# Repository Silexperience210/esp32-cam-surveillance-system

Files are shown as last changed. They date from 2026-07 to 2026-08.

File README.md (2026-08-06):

# ESP32-CAM Surveillance System

> A complete DIY smart surveillance ecosystem: ESP32-CAM cameras with Telegram alerts, a tactile multi-camera monitoring console, automatic night lighting, video recording — and a 3D-printable wall-mount case.

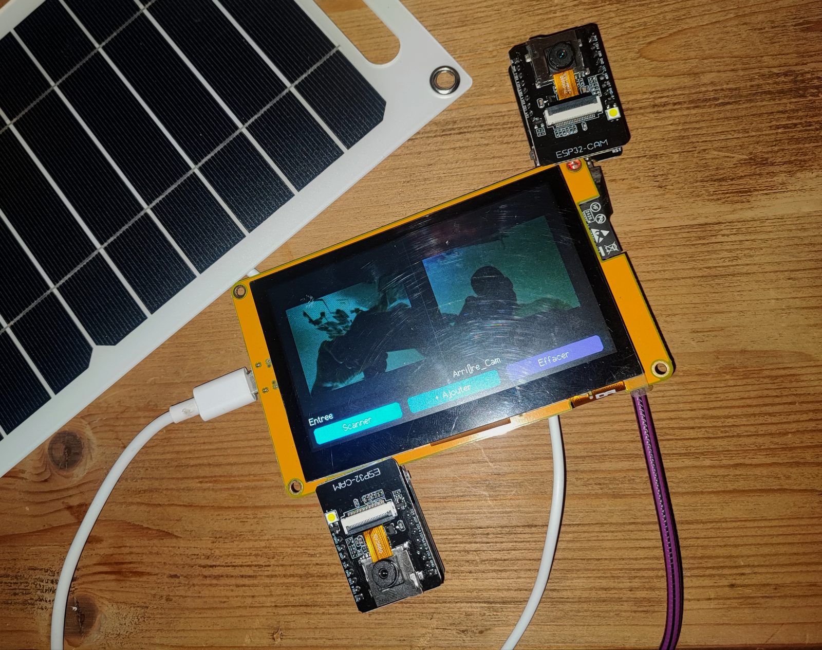
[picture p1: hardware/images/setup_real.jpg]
The running system: S3 monitor console with two ESP32-CAM cameras


---

## ✨ Features

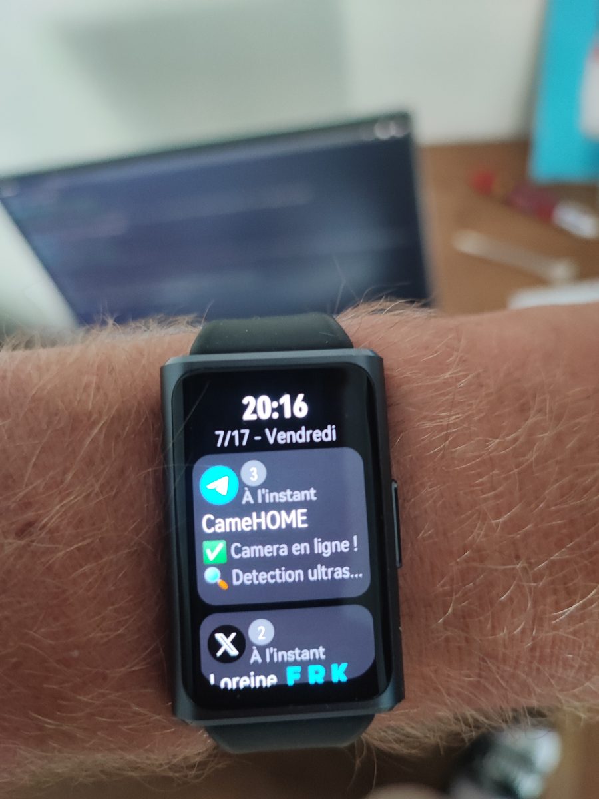
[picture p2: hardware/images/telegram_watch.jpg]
Instant Telegram alert on a smartwatch


### 📷 ESP32-CAM Camera Firmware
- **Live MJPEG streaming** in any web browser (`/stream`)
- **Telegram alerts**: instant photo + notification on presence detection (HC-SR04 ultrasonic sensor)
- **AVI video recording** to microSD while a presence is detected (5–30 s clips, 10 fps, MJPEG)
- **Two-way Telegram commands**: `/photo`, `/video`, `/status`, `/led`, `/on`, `/off`
- **LED lighting control**: manual (web / Telegram / monitor) + **automatic night mode** (lights on during alerts between 18:00 and 07:00)
- **Web configuration portal**: zero hardcoded credentials — the camera creates its own WiFi AP on first boot
- **Self-healing watchdog**: auto-restart on frozen loop, stalled stream or lost WiFi (24/7 operation)
- **Human-readable camera identity** via `/info` JSON endpoint (used by the monitor console)

_Alerts reach you anywhere — phone, desktop, even your smartwatch._

<br clear="both"/>

### 📺 ESP32-S3 Tactile Monitor (4827S043, 4.3″ 480×272)
- **Multi-camera grid view** (up to 4 cameras, round-robin refresh)
- **Tap a tile → full-screen live stream** (~10–15 fps), tap again → back to grid
- **Automatic discovery**: finds cameras instantly via **mDNS** (with IP-scan fallback)
- **On-screen keypad**: add a camera manually by IP (name auto-fetched)
- **LED toggle button** in full-screen view
- **Same web portal** for WiFi provisioning — no code editing
- Offline camera detection + auto WiFi reconnect

### 🖨️ 3D-Printed Wall-Mount Case
- Frame for the 4827S043 display + compartment for a **flat 10 000 mAh LiPo battery**
- **Dovetail wall plate**: the console slides on/off the wall in one gesture — use it as a portable tablet
- Fully **parametric OpenSCAD** source (adjust to your own battery)

### 🧠 Hermes AI Integration (NEW!)
- **YOLOv8 real-time object detection** — 80 classes, GPU-accelerated (RTX 3060), 3s inference
- **Ollama + LLaVA natural language descriptions** — « Un homme en noir tient un smartphone »
- **Motion-aware pipeline** — YOLO checks every 15s, Ollama runs only on person detection
- **Smart Telegram alerts** — silent when nothing happens, instant delivery on detection
- **AI Dashboard** — live stats, detection heatmap, multi-camera mosaic, event log
- **Detection gallery** — last 50 person snapshots with AI descriptions
- **Daily passage counter** — unique persons/vehicles with 5-min cooldown
- **Anomaly detection** — night activity, first event in 24h, activity spikes
- **Daily report** — scheduled summary at 20:00
- **Multi-camera support** — `cameras.json` config, daemon loops all enabled cameras
- **Telegram Mini App** — snapshot live, LED control, auto-refresh
- **Auto-cleanup** — keeps 7 days of snapshots, only saves person detections

> See [`hermes-ai/README.md`](hermes-ai/README.md) for setup instructions.

---

## 🏗️ System Architecture

```
                 WiFi LAN
 ┌──────────────────────────────────────────────────┐
 │                                                  │
 │   ESP32-CAM #1          ESP32-CAM #2             │
 │   ┌──────────────┐      ┌──────────────┐         │
 │   │ OV3660       │      │ OV3660       │         │
 │   │ HC-SR04      │      │ HC-SR04      │         │
 │   │ LED lighting │      │ microSD      │         │
 │   └──────┬───────┘      └──────┬───────┘         │
 │          │ MJPEG/JSON           │                │
 │          ▼                      ▼                │
 │   ┌───────────────────────────────────┐          │
 │   │  ESP32-S3 Monitor (4827S043)      │          │
 │   │  grid view · full-screen · scan   │          │
 │   └───────────────────────────────────┘          │
 │                                                  │
 └──────────────────────────────────────────────────┘
                          │
                          ▼ HTTPS
                   Telegram Bot API
              (alerts, photos, videos, commands)
```

---

## 🧰 Hardware Requirements

| Qty | Part | Notes |
|----:|---|---|
| 1+ | ESP32-CAM (AI-Thinker / Binghe) + OV3660 | One per camera |
| 1 | ESP32-4827S043 (ESP32-S3 + 4.3″ capacitive touch) | Monitor console |
| 1+ | HC-SR04 ultrasonic sensor | Presence detection (optional) |
| 1+ | microSD card (FAT32, ≤ 32 GB) | Video recording (optional) |
| 1 | LED (+ 220 Ω resistor) or onboard flash LED | Night lighting |
| 1 | Flat 10 000 mAh LiPo battery | For the portable console |
| — | FTDI programmer / USB cables | Flashing |

---

## 🚀 Getting Started

### 1. Flash the camera

```bash
arduino-cli compile --fqbn esp32:esp32:esp32cam firmware/esp32-cam
arduino-cli upload  --fqbn esp32:esp32:esp32cam -p COMx firmware/esp32-cam
```

> Flashing an ESP32-CAM requires **GPIO 0 → GND** at boot. **Remove the jumper and press RESET afterwards**, otherwise the board stays in download mode.

### 2. Configure via the web portal (no code editing!)

1. On first boot, the camera creates the WiFi network **`ESP32-CAM-Setup-xxxx`** (password: `12345678`)
2. Connect and open **http://192.168.4.1**
3. Fill in: **WiFi credentials**, **Telegram bot token + chat ID**, **camera name**, detection distance
4. The camera reboots onto your LAN and sends *"✅ Camera online"* to your Telegram

The same portal stays available anytime at `http://<camera-ip>/setup`.

### 3. Create the Telegram bot (5 min)

1. In Telegram, open **@BotFather** → `/newbot` → copy the **token**
2. Send any message to your new bot
3. Get your **chat ID** instantly from **@userinfobot**
4. Enter both values in the web portal

### 4. Flash the S3 monitor

```bash
arduino-cli lib install "LovyanGFX"
arduino-cli compile --fqbn "esp32:esp32:esp32s3:FlashSize=8M,PSRAM=opi,PartitionScheme=huge_app,CPUFreq=240,USBMode=hwcdc,CDCOnBoot=cdc" firmware/esp32-s3-monitor
arduino-cli upload  --fqbn "esp32:esp32:esp32s3:FlashSize=8M,PSRAM=opi,PartitionScheme=huge_app,CPUFreq=240,USBMode=hwcdc,CDCOnBoot=cdc" -p COMx firmware/esp32-s3-monitor
```

Board options: **ESP32S3 Dev Module**, PSRAM **OPI**, Flash **8MB** (N8R8) or 16MB (N16R8), partition **Huge APP**, USB CDC On Boot **Enabled**.

On first boot the monitor shows its own provisioning screen (`ESP32-Viewer-Setup-xxxx`, same procedure). Then tap **[Scanner]** — it discovers your cameras automatically.

---

## 🤖 Telegram Commands

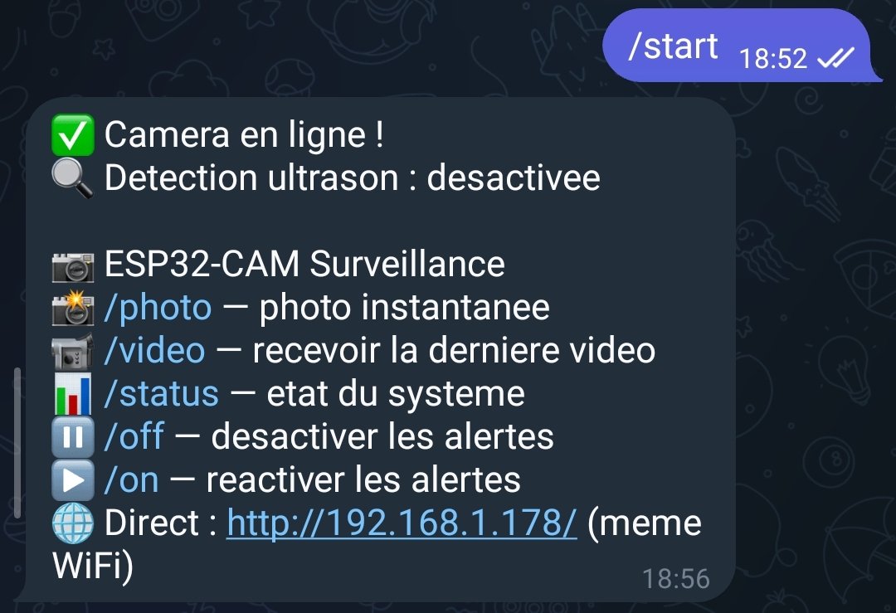
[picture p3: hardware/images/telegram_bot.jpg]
Telegram bot: boot message and command list


| Command | Action |
|---|---|
| `/photo` | Instant photo from the camera |
| `/video` | Receive the last recorded AVI clip |
| `/led` `/ledon` `/ledoff` `/ledauto` | Lighting control |
| `/on` `/off` | Enable / disable automatic alerts |
| `/status` | IP, uptime, distance, SD, videos, LED, night mode |
| `/help` | Command list |

## 🌐 Camera HTTP API

| Endpoint | Description |
|---|---|
| `GET /` | Web dashboard (live view + links) |
| `GET /stream` | MJPEG live stream |
| `GET /capture` | Single JPEG snapshot |
| `GET /video` | Download last AVI recording |
| `GET /list` | List/download all recordings |
| `GET /led?state=on\|off\|toggle\|auto` | Lighting control (JSON) |
| `GET /info` | Camera identity + state (JSON) |
| `GET /setup` | Configuration portal |

---

## 🔌 Wiring

### HC-SR04 ultrasonic sensor (optional — presence detection)

```
HC-SR04          ESP32-CAM
-------          ---------
VCC    ────────► 5V
GND    ────────► GND
TRIG   ────────► GPIO 13
ECHO   ──[1kΩ]──► GPIO 12 ──[2kΩ]──► GND     ← voltage divider (mandatory)
```

> ⚠️ ECHO outputs 5 V — the divider protects the 3.3 V GPIO. The microSD slot works in **1-bit mode**, leaving GPIO 12/13 free.

Then set `DETECTION_ULTRASON = true` in the camera firmware and reflash.

### LED lighting

Use the onboard flash LED (GPIO 4) directly, or wire an external LED:

```
LED anode (+) ──[220Ω]── GPIO 4
LED cathode (−) ──────── GND
```

Both light up together — perfect for night illumination. For a high-power LED, drive it through an NPN transistor.

**Automatic night mode**: on any alert between **18:00 and 07:00**, the LED turns on for the photo and the whole video, then switches off. Manual control always takes priority.

---

## 🖨️ 3D-Printed Cases

### Monitor case (wall-mount / tabletop)

Parametric OpenSCAD source + ready-to-print STLs in [`hardware/case/`](hardware/case).

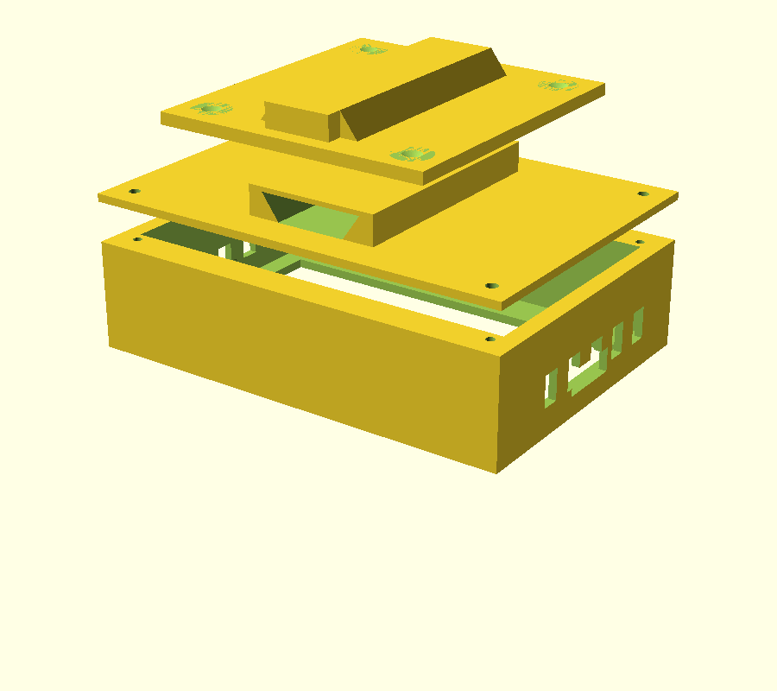
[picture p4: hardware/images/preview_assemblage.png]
Case preview


| Part | File | Print orientation |
|---|---|---|
| Main body | `boitier_corps.stl` | Screen frame facing the bed |
| Back cover (dovetail female) | `boitier_couvercle.stl` | Rail facing up |
| Wall plate (dovetail male) | `boitier_plaque_murale.stl` | Flat, rail facing up |

- No supports needed · PLA/PETG · 0.2 mm layers · 3 walls · 20 % infill
- Assembly: 4× M2 self-tapping screws (cover), 4× wood screws (wall plate)
- **Battery**: measure yours and adjust `bat_w / bat_h / bat_d` in `boitier_4827S043.scad`, then re-export:

```bash
openscad -o boitier_corps.stl -D part=1 boitier_4827S043.scad
```

### Camera case (ESP32-CAM + programming board)

Snap-fit enclosure for an ESP32-CAM stacked on its **ESP32-CAM-MB USB programming board** — thin **1.6 mm walls** with a vertical ribbed texture. STLs + parametric source in [`hardware/case-esp32cam/`](hardware/case-esp32cam).

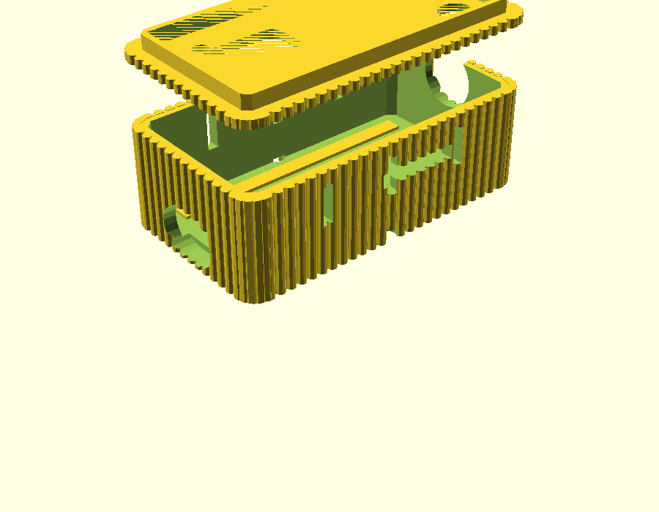
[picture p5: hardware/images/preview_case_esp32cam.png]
Camera case preview


| Part | File | Print orientation |
|---|---|---|
| Body | `esp32cam_case_body.stl` | Upright, bottom on the bed |
| Friction lid | `esp32cam_case_lid.stl` | Plate on the bed |

- No supports · PLA/PETG · 0.2 mm layers · ~1h30 total
- Lens / flash / micro-USB / microSD / antenna openings + 2× M3 mount holes
- **Measure your stack** and adjust `in_l / in_w / in_h`, `cam_z`, `lid_clr`… at the top of `esp32cam_mb_case.scad`

---

## 📁 Project Structure

```
esp32-cam-surveillance-system/
├── firmware/
│   ├── esp32-cam/              # Camera firmware (Arduino)
│   │   ├── esp32-cam-surveillance.ino
│   │   └── avi_writer.h        # Minimal MJPEG→AVI writer
│   └── esp32-s3-monitor/       # Tactile monitor firmware (LovyanGFX)
│       └── esp32-viewer-s3.ino
├── hardware/
│   ├── case/                   # Monitor case (OpenSCAD + STLs)
│   ├── case-esp32cam/          # Camera case for ESP32-CAM + MB board
│   └── images/                 # Renders & sample captures
├── docs/
├── LICENSE
└── README.md
```

## 🧠 Design Notes

- **Grid refresh** uses per-camera `/capture` round-robin (light on bandwidth); **full-screen** uses the dedicated MJPEG `/stream`.
- The microSD slot runs in **1-bit SD_MMC mode**, keeping GPIO 12/13 free for the ultrasonic sensor.
- AVI files use a minimal MJPEG writer (`avi_writer.h`) — playable in VLC and shareable via Telegram.
- All credentials persist in **NVS (Preferences)** — survives power loss, no SD dependency.
- The watchdog task runs on the **second core**, so even a fully frozen main loop gets restarted.

## 🗺️ Roadmap

- [ ] PIR wake-up + deep sleep for battery-powered cameras
- [ ] Home Assistant integration (MJPEG camera + MQTT alerts)
- [ ] Remote access via Tailscale
- [ ] Auto full-screen on the monitor when a camera triggers
- [x] mDNS camera auto-discovery (instant — cameras also reachable at `http://<name>.local`)

## ⚠️ Disclaimer

This is a DIY hobby project. Do not use it as your only security system. Respect privacy laws when installing cameras.

## 📄 License

MIT License — see [LICENSE](LICENSE).

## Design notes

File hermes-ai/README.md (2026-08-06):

# Hermes AI — Intégration ESP32-CAM

Pipeline IA complet pour caméra de surveillance ESP32-CAM, piloté par l'agent Hermes.

## 🧠 Fonctionnalités

- **Motion detection** → ne déclenche l'analyse que si mouvement (CPU, ~1.4s)
- **YOLOv8** → détection 80 classes (personne, voiture, animal...) en ~3s GPU
- **Ollama + LLaVA** → descriptions naturelles en français (~5s)
- **Alertes intelligentes** → ne notifie que personne/véhicule/animal
- **Compteur de passages** → cooldown 5 min entre chaque comptage
- **Anomalies** → personne la nuit, pic d'activité
- **Dashboard web** → stats, événements, heatmap, toggle ON/OFF
- **Mini App Telegram** → snapshot live, contrôle LED
- **Silencieux si RAS** → 0 message si rien ne se passe

## 📁 Structure

```
hermes-ai/
├── scripts/
│   ├── ai_eye.py          → Pipeline IA principal (motion → YOLO → Ollama → alerte)
│   ├── camera_client.py   → Client HTTP pour l'ESP32-CAM
│   ├── eye_proxy.py       → Proxy Flask (Mini App + API dashboard)
│   ├── ai_smart_cron.sh   → Cron silencieux (alerte uniquement)
│   ├── camera_health.sh   → Health check caméra
│   └── ai_cleanup.sh      → Nettoyage snapshots >7j
└── dashboards/
    ├── eye.html            → Dashboard full (stream MJPEG)
    ├── eye_telegram.html   → Mini App Telegram (mobile)
    └── ai_dashboard.html   → Dashboard IA (stats, events, heatmap)
```

## 🚀 Quick Start

```bash
# 1. Installer les dépendances
uv pip install ultralytics torch torchvision Pillow numpy flask

# 2. Ollama (pour LLaVA)
ollama pull llava-llama3:8b

# 3. Lancer le proxy
python3 eye_proxy.py

# 4. Activer l'IA
python3 ai_eye.py --on

# 5. Analyse unique
python3 ai_eye.py

# 6. Status
python3 ai_eye.py --status
```

## 🔧 Commandes

| Commande | Action |
|---|---|
| `ai_eye.py --on` | Activer l'IA |
| `ai_eye.py --off` | Suspendre l'IA |
| `ai_eye.py --status` | État GPU, événements, snapshots |
| `ai_eye.py --cleanup 7` | Nettoyer les fichiers >7 jours |
| `camera_client.py capture` | Photo instantanée |
| `camera_client.py motion` | Détection de mouvement |
| `camera_client.py health` | Vérifier si la caméra est en ligne |

## 🌐 Endpoints (proxy Flask :8084)

| URL | Description |
|-----|---|
| `/` | Mini App Telegram |
| `/dashboard` | Dashboard IA |
| `/api/capture` | Snapshot JPEG |
| `/api/info` | Infos caméra |
| `/api/led?state=toggle` | Contrôle LED |
| `/api/ai/status` | Statut IA (GPU, events) |
| `/api/ai/events` | Derniers événements |
| `/api/ai/counter` | Compteur passages |
| `/api/ai/report` | Rapport 24h |
| `/api/ai/toggle` | ON/OFF IA |
| `/api/ai/analyze` | Forcer analyse |

## 📊 Crons recommandés

| Cron | Fréquence | Script |
|---|---|---|
| AI Eye | 5 min | `ai_smart_cron.sh` |
| Health check | 5 min | `camera_health.sh` |
| Nettoyage | 3h du matin | `ai_cleanup.sh` |
| Rapport quotidien | 20h | prompt LLM → `/api/ai/report` |

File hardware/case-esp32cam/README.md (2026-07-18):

# 📦 ESP32-CAM + ESP32-CAM-MB Case

Two-piece enclosure for an **ESP32-CAM (AI-Thinker) stacked on its ESP32-CAM-MB USB programming board** — thin **1.6 mm walls** with a clean **vertical ribbed texture** outside.

exploded preview

## 📁 Files

| File | Description |
|---|---|
| `esp32cam_mb_case.scad` | Fully **parametric** OpenSCAD source |
| `esp32cam_case_body.stl` | Main body — 59.3 × 33 × 18.7 mm |
| `esp32cam_case_lid.stl` | Snap-friction lid — 4.2 mm |
| `esp32cam_case_print_all.stl` | Both parts side by side (single plate) |

## 🖨️ Printing

- **No supports** — body upright (bottom on the bed), lid plate on the bed
- PLA or PETG · **0.2 mm** layers · 3–4 perimeters (1.6 mm walls = 4 × 0.4 lines)
- Infill doesn't matter (walls are solid)
- ~1h30 total print time

## 📐 Dimensions

- Outside: **59.3 × 33 × 20.2 mm** (ribs included)
- Inside: 54.5 × 28.2 × 17 mm (fits the MB board 52.5 × 26 mm + stacked camera)

## ✨ Features

- Ø11 mm **lens window** (front face)
- **Flash LED window** in the lid (`top_flash`, AI-Thinker LED shines upwards — set `front_flash=true` if yours faces forward)
- **Micro-USB** slot (rear face) + pin-hole for the MB **reset button**
- Side **microSD slot** — insert/remove the card without opening the case
- **WiFi antenna window** in the lid (better signal)
- 6 side **ventilation slots**
- 2× **M3 holes** in the bottom (wall/desk mounting)
- **Friction-fit lid** — no screws, no hardware

## ⚠️ Measure before printing

Default dimensions match the standard AI-Thinker + MB stack. Check yours and adjust at the top of `esp32cam_mb_case.scad`:

| Parameter | Default | Check |
|---|---|---|
| `in_l / in_w / in_h` | 54.5 / 28.2 / 17 | Your MB board size + total stack height |
| `cam_z` | 14.5 | Lens center height (from inside bottom) |
| `cam_y` | 0 | Lens lateral offset |
| `flash_x / flash_y` | 20 / -8.5 | Flash LED position |
| `usb_z` | 5 | Micro-USB connector height |
| `sd_x / sd_z` | 5 / 12.3 | microSD slot position (left wall) |
| `lid_clr` | 0.25 | Lid clearance — **+0.05 if too tight, -0.05 if too loose** |

## 🔧 Re-export STLs

```bash
openscad -o esp32cam_case_body.stl -D part=1 esp32cam_mb_case.scad   # body
openscad -o esp32cam_case_lid.stl  -D part=2 esp32cam_mb_case.scad   # lid
openscad -o esp32cam_case_print_all.stl -D part=3 esp32cam_mb_case.scad  # both
```

## 🎨 Texture tuning

- `rib_step = 2.1` → rib spacing (larger = airier, smaller = finer)
- `rib_r = 0.85` → rib depth
- `rib = false` → smooth case

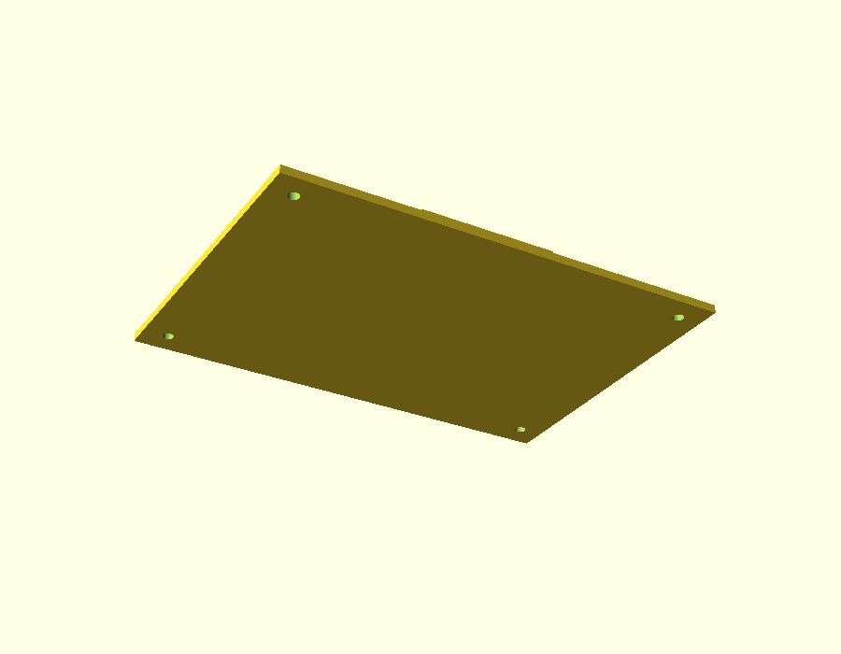
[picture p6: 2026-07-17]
hardware/images/preview_couvercle.png

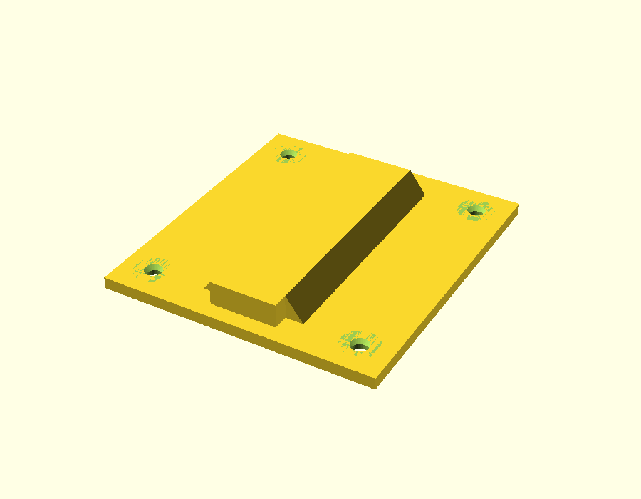
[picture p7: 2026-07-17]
hardware/images/preview_plaque.png

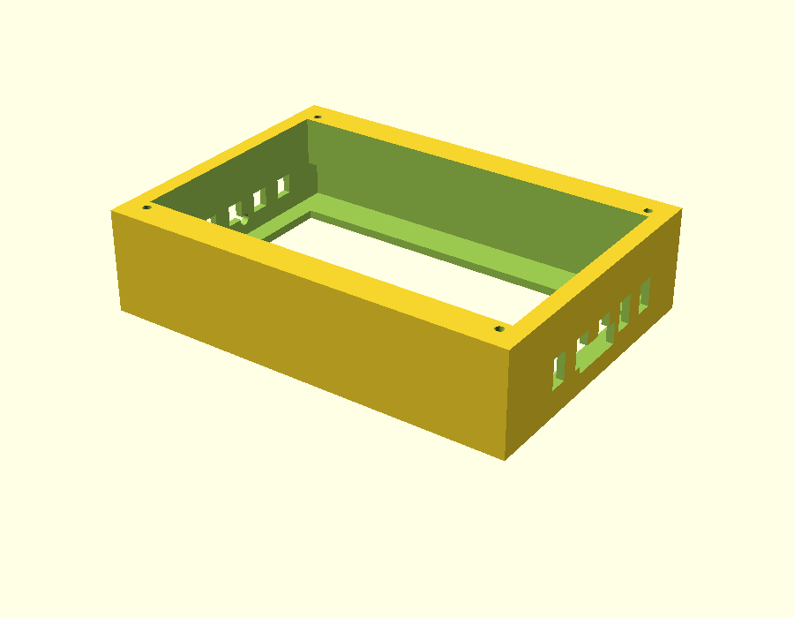
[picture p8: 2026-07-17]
hardware/images/preview_corps.png

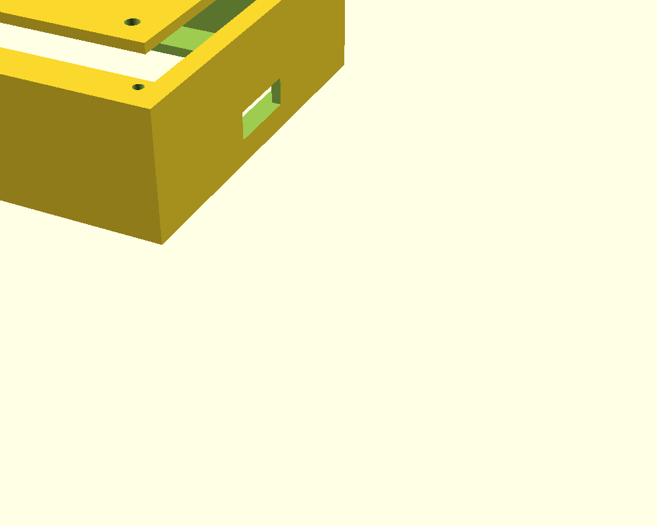
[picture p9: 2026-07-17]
hardware/images/preview_boitier.png

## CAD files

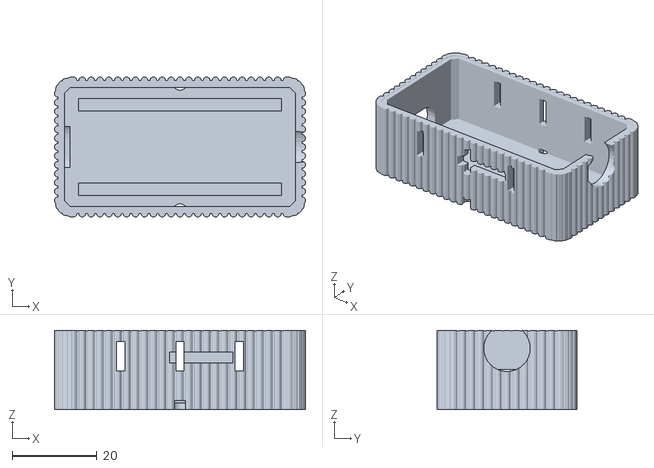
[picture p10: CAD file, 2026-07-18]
hardware/case-esp32cam/esp32cam_case_body.stl
59.3 x 33.0 x 18.7

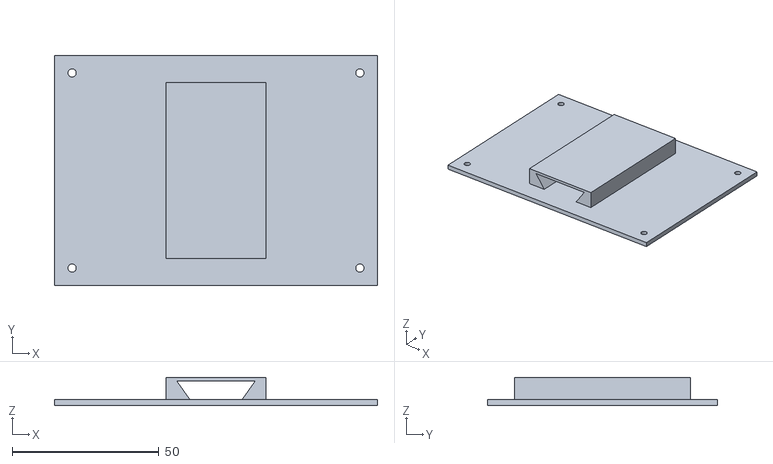
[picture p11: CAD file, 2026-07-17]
hardware/case/boitier_couvercle.stl
109.9 x 78.4 x 9.55

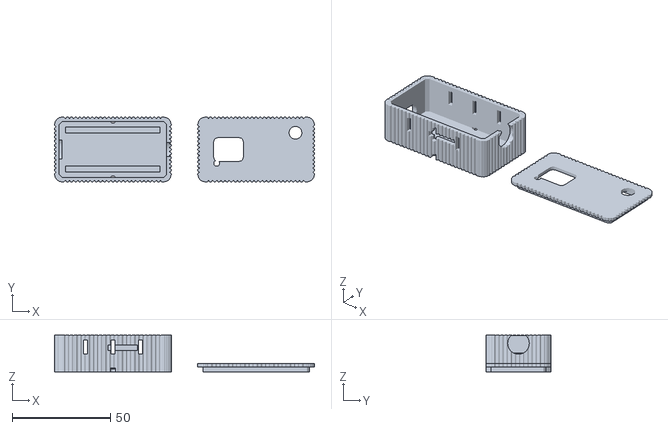
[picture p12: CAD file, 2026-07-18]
hardware/case-esp32cam/esp32cam_case_print_all.stl
132.0 x 33.0 x 18.7

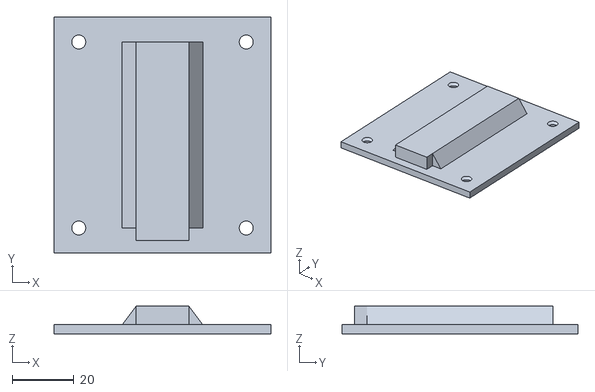
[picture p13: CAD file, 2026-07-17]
hardware/case/boitier_plaque_murale.stl
70.0 x 76.0 x 9.00

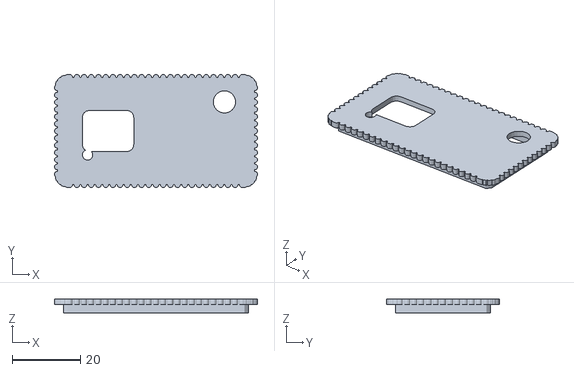
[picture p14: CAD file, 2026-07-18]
hardware/case-esp32cam/esp32cam_case_lid.stl
59.3 x 33.0 x 4.19

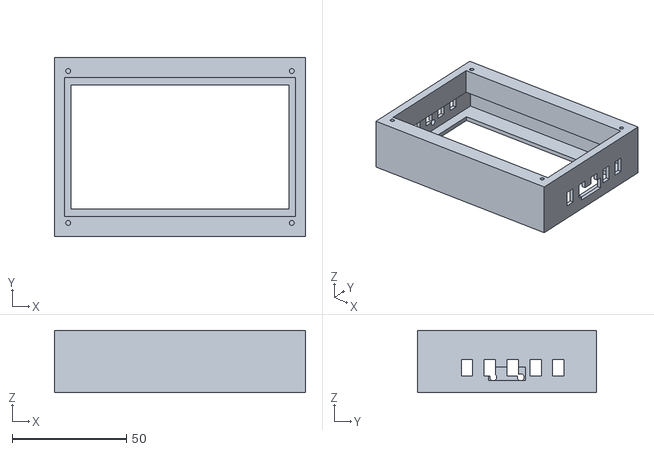
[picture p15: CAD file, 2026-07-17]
hardware/case/boitier_corps.stl
109.9 x 78.4 x 27.2

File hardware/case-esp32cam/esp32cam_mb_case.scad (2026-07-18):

// =====================================================================
//  BOITIER ESP32-CAM + CARTE PROGRAMMATION ESP32-CAM-MB
//  Parois fines 1.6 mm - Texture stries verticales - Couvercle friction
//  IMPRESSION : corps + couvercle, aucun support, PLA/PETG 0.2 mm
// =====================================================================
//  ⚠️  COTES PAR DÉFAUT = montage standard AI-Thinker + MB.
//      MESURE ton empilage et ajuste les variables ci-dessous.
// =====================================================================

// ---------- CHOIX DE LA PIÈCE ----------
part = 3;        // 1 = corps | 2 = couvercle | 3 = les deux (impression) | 4 = éclaté (vérif)

// ---------- COTES INTERNES (À MESURER) ----------
in_l = 54.5;     // longueur interne  (carte MB ≈ 52.5 + jeu)
in_w = 28.2;     // largeur interne   (carte MB ≈ 26   + jeu)
in_h = 17.0;     // hauteur interne   (empilage MB + ESP32-CAM + nappe)

wall   = 1.6;    // épaisseur des parois  ← ta demande
corner = 3.0;    // rayon des coins extérieurs

// ---------- CAMÉRA (face avant) ----------
cam_z  = 14.5;   // hauteur du centre de la lentille (depuis le fond interne)
cam_y  = 0;      // décalage latéral lentille (0 = centrée)
lens_d = 11;     // diamètre fenêtre lentille

// ---------- LED FLASH GPIO4 ----------
top_flash   = true;    // fenêtre dans le COUVERCLE (LED AI-Thinker émet vers le haut)
front_flash = false;   // fenêtre dans la face avant (si LED orientée avant)
flash_x  = 20;         // position X de la LED (vers l'avant, côté connecteur cam)
flash_y  = -8.5;       // position Y de la LED
flash_d  = 6.5;        // diamètre fenêtre flash

// ---------- USB (face arrière) ----------
usb_w = 13;      // largeur fenêtre micro-USB
usb_h = 9;       // hauteur fenêtre
usb_z = 5;       // hauteur du centre (connecteur au bas de la MB)

// ---------- OPTIONS ----------
vent         = true;   // fentes de ventilation sur les côtés
sd_slot      = true;   // fente carte microSD (paroi gauche)
sd_x   = 5;  sd_z = 12.3;  sd_len = 15;  sd_h = 2.6;   // position fente SD
reset_hole   = true;   // trou d'aiguille pour bouton reset MB (couvercle)
reset_x = -20;  reset_y = 7;  reset_d = 3;
ant_window   = true;   // fenêtre antenne WiFi (couvercle, améliore le signal)
ant_x = -14; ant_w = 15; ant_h = 12;
mount_holes  = true;   // 2 trous M3 dans le fond (fixation)
mount_spacing = 30;

// ---------- COUVERCLE ----------
lid_lip = 2.6;   // hauteur de la lèvre d'emboîtement
lid_clr = 0.25;  // jeu friction (±0.05 selon imprimante — resserre si trop lâche)

// ---------- TEXTURE STRIES ----------
rib      = true;
rib_step = 2.1;  // espacement des stries (mm)
rib_r    = 0.85; // rayon des stries = profondeur du relief

// =====================================================================
//  CALCULS
// =====================================================================
out_l  = in_l + 2*wall;
out_w  = in_w + 2*wall;
body_h = in_h + wall;           // hauteur du corps (fond compris)

// =====================================================================
//  MODULES DE BASE
// =====================================================================
// Profil 2D arrondi du boîtier ; d>0 grossit, d<0 rétrécit
module profil(d=0) {
  offset(r = corner + d)
    square([out_l - 2*corner, out_w - 2*corner], center = true);
}

// Coque du corps (bac ouvert)
module coque() {
  difference() {
    linear_extrude(body_h) profil(0);
    translate([0, 0, wall])
      linear_extrude(body_h) profil(-wall);
  }
}

// Rails de support de la carte MB (évite les soudures des headers)
module rails() {
  for (s = [-1, 1])
    translate([0, s * 10, wall])
      cube([48, 3, 1.2], center = true);
}

// Stries verticales : cylindres posés EXACTEMENT sur le périmètre
// (segments droits + quarts de cercle aux coins -> ancrage garanti)
rl = out_l/2 - corner;      // demi-longueur des parties droites
rw = out_w/2 - corner;
nl = floor(rl / rib_step);  // nb stries par demi-face longue
nw = floor(rw / rib_step);  // nb stries par demi-face courte
na = max(4, round(PI*corner/2 / rib_step)); // stries par quart de coin

module strie(x, y, h)
  translate([x, y, -0.1]) cylinder(r = rib_r, h = h + 0.2, $fn = 10);

module stries(h) {
  intersection() {
    union() {
      // faces longues (y = ±out_w/2)
      for (s = [-1, 1], i = [-nl : nl])
        strie(i * rib_step, s * out_w/2, h);
      // faces courtes (x = ±out_l/2)
      for (s = [-1, 1], i = [-nw : nw])
        strie(s * out_l/2, i * rib_step, h);
      // quarts de cercle aux 4 coins
      for (cx = [-1, 1], cy = [-1, 1], a = [0 : na])
        strie(cx * (rl + corner * cos(a * 90 / na)),
              cy * (rw + corner * sin(a * 90 / na)), h);
    }
    // on ne garde que ce qui dépasse de la surface (ancrage 0.5 mm)
    difference() {
      linear_extrude(h + 0.2) profil(rib_r * 0.95);
      translate([0, 0, -0.1]) linear_extrude(h + 0.4) profil(-0.5);
    }
  }
}

// =====================================================================
//  OUVERTURES DU CORPS
// =====================================================================
module ouvertures_corps() {
  // --- Fenêtre lentille (face avant +X) ---
  translate([out_l/2, cam_y, cam_z])
    rotate([0, 90, 0])
      cylinder(d = lens_d, h = wall*3 + 1, center = true, $fn = 32);

  // --- Fenêtre flash LED face avant (option) ---
  if (front_flash)
    translate([out_l/2, flash_y, cam_z])
      rotate([0, 90, 0])
        cylinder(d = flash_d, h = wall*3 + 1, center = true, $fn = 24);

  // --- Fenêtre micro-USB (face arrière -X), oblongue ---
  translate([-out_l/2, 0, usb_z])
    rotate([0, 90, 0])
      hull()
        for (s = [-1, 1])
          translate([0, s * (usb_w - usb_h)/2, 0])
            cylinder(d = usb_h, h = wall*3 + 1, center = true, $fn = 24);

  // --- Fentes de ventilation (2 grands côtés, partie haute) ---
  if (vent)
    for (s = [-1, 1], j = [-1, 0, 1])
      translate([j * 14, s * out_w/2, body_h - 6])
        cube([2, wall*3 + 1, 7], center = true);

  // --- Fente carte microSD (paroi gauche -Y) ---
  if (sd_slot)
    translate([sd_x, -out_w/2, sd_z])
      cube([sd_len, wall*3 + 1, sd_h], center = true);

  // --- Trous de fixation M3 dans le fond ---
  if (mount_holes)
    for (s = [-1, 1])
      translate([0, s * mount_spacing/2, -0.5])
        cylinder(d = 3.2, h = wall + 1, $fn = 24);
}

// =====================================================================
//  CORPS
// =====================================================================
module corps() {
  difference() {
    union() {
      coque();
      rails();
      if (rib) stries(body_h);
    }
    ouvertures_corps();
  }
}

// =====================================================================
//  COUVERCLE (emboîtement friction)
// =====================================================================
module couvercle() {
  difference() {
    union() {
      // plaque
      linear_extrude(wall) profil(0);
      // lèvre d'emboîtement (rentre dans le corps)
      translate([0, 0, wall - 0.01])
        difference() {
          linear_extrude(lid_lip) profil(-wall - lid_clr);
          linear_extrude(lid_lip) profil(-wall - lid_clr - 1.1);
        }
      // stries sur le pourtour de la plaque
      if (rib)
        intersection() {
          stries(wall);
          linear_extrude(wall) profil(rib_r);
        }
    }
    // --- fenêtre flash LED (dessus) ---
    if (top_flash)
      translate([flash_x, flash_y, -0.5])
        cylinder(d = flash_d, h = wall + 1, $fn = 24);
    // --- trou bouton reset MB ---
    if (reset_hole)
      translate([reset_x, reset_y, -0.5])
        cylinder(d = reset_d, h = wall + 1, $fn = 20);
    // --- fenêtre antenne WiFi ---
    if (ant_window)
      translate([ant_x, 0, -0.5])
        hull()
          for (sx = [-1, 1], sy = [-1, 1])
            translate([sx * (ant_w/2 - 2), sy * (ant_h/2 - 2), 0])
              cylinder(r = 2, h = wall + 1, $fn = 16);
  }
}

// =====================================================================
//  RENDU
// =====================================================================
if (part == 1) corps();
else if (part == 2)
  translate([0, 0, wall + lid_lip]) rotate([180, 0, 0]) couvercle(); // à plat pour impression
else if (part == 3) {
  corps();
  translate([out_l/2 + 15 + out_l/2, 0, wall + lid_lip])
    rotate([180, 0, 0]) couvercle();
}
else if (part == 4) { // éclaté de vérification
  corps();
  translate([0, 0, body_h + 12]) couvercle();
}

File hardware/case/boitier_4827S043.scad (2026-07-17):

// ============================================================
// BOITIER ESP32-4827S043 + Batterie 10000mAh + Fixation murale
// Moniteur multi-cameras — version "tablette murale detachable"
// ============================================================
// 3 pieces a imprimer :
//   part=1 -> corps (cadre ecran + logement carte + batterie)
//   part=2 -> couvercle arriere (avec rail femelle)
//   part=3 -> plaque murale (avec rail male, a visser au mur)
//
// Le boitier glisse de haut en bas sur la plaque murale et se
// detache facilement pour etre utilise comme tablette.
// ============================================================

part = 0;   // 0 = vue eclatee, 1/2/3 = piece a exporter

// ---------- MESURES A AJUSTER (mm) ----------
pcb_w = 105.5;   // largeur carte 4827S043
pcb_h = 74.0;    // hauteur carte
pcb_d = 12.0;    // epaisseur carte+ecran+composants
scr_w = 95.5;    // fenetre ecran visible (95.04 + jeu)
scr_h = 54.5;    // (53.86 + jeu)
scr_offx = 0;    // decalage fenetre ecran X si besoin
scr_offy = 0;    // decalage fenetre ecran Y si besoin

// Batterie 10000mAh plate LiPo : MESURE LA TIENNE et ajuste !
bat_w = 101.0;   // longueur batterie
bat_h = 61.0;    // largeur batterie
bat_d = 13.0;    // epaisseur batterie

wall   = 2.0;    // epaisseur parois laterales
front  = 2.2;    // epaisseur face avant (cadre)
gap    = 0.4;    // jeu d'assemblage carte

// ---------- dimensions calculees ----------
ext_w = pcb_w + 2*wall + gap;          // largeur externe boitier
ext_h = pcb_h + 2*wall + gap;          // hauteur externe
depth = front + pcb_d + bat_d + wall;  // profondeur totale ~29mm

// ---------- rail queue d'aronde (murale) ----------
rail_len  = 60;   // longueur du rail (glissement vertical)
rail_wb   = 26;   // largeur a la base (contre la plaque)
rail_wt   = 17;   // largeur au sommet
rail_h    = 6;    // hauteur du rail
rail_play = 0.35; // jeu coulissant

// ---------- vis ----------
boss_d  = 6;      // diametre boss de fixation couvercle
screw_d = 2.2;    // trou vis M2 auto-taraudeuse
mwall_d = 4.5;    // trous vis murale (vis bois 4mm)

$fn = 48;

// ============================================================
module corps() {
  difference() {
    union() {
      translate([-ext_w/2, -ext_h/2, 0])
        cube([ext_w, ext_h, depth - wall]);
      for (x = [-1, 1], y = [-1, 1])
        translate([x*(ext_w/2 - wall - boss_d/2 - 1),
                   y*(ext_h/2 - wall - boss_d/2 - 1), 0])
          cylinder(d = boss_d, h = depth - wall);
    }
    // cavite carte (derriere le cadre avant)
    translate([-pcb_w/2 - gap/2, -pcb_h/2 - gap/2, front])
      cube([pcb_w + gap, pcb_h + gap, pcb_d + 0.2]);
    // cavite batterie
    translate([-bat_w/2, -bat_h/2, front + pcb_d])
      cube([bat_w, bat_h, bat_d + 0.2]);
    // fenetre ecran
    translate([-scr_w/2 + scr_offx, -scr_h/2 + scr_offy, -0.1])
      cube([scr_w, scr_h, front + 0.2]);
    // ouverture USB-C (cote droit)
    translate([ext_w/2 - wall - 0.1, -8, front + pcb_d/2 - 3])
      cube([wall + 0.2, 16, 6]);
    // trous acces boutons RESET / BOOT (cote gauche)
    for (y = [-6, 6])
      translate([-ext_w/2 - 0.1, y, front + pcb_d/2 - 1.5])
        rotate([0, 90, 0]) cylinder(d = 3, h = wall + 0.2);
    // trous vis couvercle dans les boss
    for (x = [-1, 1], y = [-1, 1])
      translate([x*(ext_w/2 - wall - boss_d/2 - 1),
                 y*(ext_h/2 - wall - boss_d/2 - 1), depth - wall - 8])
        cylinder(d = screw_d, h = 8.1);
    // fentes de ventilation laterales (2 grands cotes, zone carte)
    for (y = [-20, -10, 0, 10, 20]) {
      translate([ext_w/2 - wall - 0.1, y, front + pcb_d/2 - 1])
        cube([wall + 0.2, 5, 8]);
      translate([-ext_w/2 - 0.1, y, front + pcb_d/2 - 1])
        cube([wall + 0.2, 5, 8]);
    }
  }
}

// ============================================================
// Rainure femelle : ETROITE a l'ouverture, LARGE au fond
// (complementaire du rail male : large a la base, etroit au sommet)
module rail_femelle(l) {
  linear_extrude(height = l)
    polygon([[-rail_wt/2 - rail_play, 0],
             [-rail_wb/2 - rail_play, rail_h + rail_play],
             [ rail_wb/2 + rail_play, rail_h + rail_play],
             [ rail_wt/2 + rail_play, 0]]);
}

module couvercle() {
  joug_h = rail_h + rail_play + 1.2;
  difference() {
    union() {
      // plaque
      translate([-ext_w/2, -ext_h/2, 0])
        cube([ext_w, ext_h, wall]);
      // joug autour du rail femelle
      translate([-rail_wb/2 - 4, -rail_len/2, wall])
        cube([rail_wb + 8, rail_len, joug_h]);
    }
    // rainure femelle traversante (le long de Y, profil dans XZ)
    translate([0, rail_len/2 + 0.1, wall])
      rotate([90, 0, 0])
        rail_femelle(rail_len + 0.2);
    // trous vis aux coins (alignes sur les boss du corps)
    for (x = [-1, 1], y = [-1, 1])
      translate([x*(ext_w/2 - wall - boss_d/2 - 1),
                 y*(ext_h/2 - wall - boss_d/2 - 1), -0.1])
        cylinder(d = screw_d + 0.6, h = wall + 0.2);
  }
}

// ============================================================
module rail_male(l) {
  // trapeze : base large (contre plaque), sommet etroit
  linear_extrude(height = l)
    polygon([[-rail_wb/2, 0], [-rail_wt/2, rail_h],
             [ rail_wt/2, rail_h], [ rail_wb/2, 0]]);
}

module plaque_murale() {
  pw = 70; ph = rail_len + 16; pt = 3;   // plaque 70 x 76 x 3
  difference() {
    union() {
      translate([-pw/2, -ph/2, 0])
        cube([pw, ph, pt]);
      // rail male COUCHE le long de Y (boitier glisse de haut en bas)
      translate([0, rail_len/2, pt])
        rotate([90, 0, 0])
          rail_male(rail_len);
      // butee basse (fin de course du boitier)
      translate([-rail_wt/2, -rail_len/2 - 4, pt])
        cube([rail_wt, 4, rail_h]);
    }
    // 4 trous de vis fraises pour fixation murale
    for (x = [-1, 1], y = [-1, 1])
      translate([x*(pw/2 - 8), y*(ph/2 - 8), -0.1]) {
        cylinder(d = mwall_d, h = pt + 0.2);
        translate([0, 0, pt - 1.6])
          cylinder(d1 = mwall_d, d2 = mwall_d*2.1, h = 1.7);   // fraisage
      }
  }
}

// ============================================================
// ---------- rendu ----------
if (part == 1) {
  corps();
} else if (part == 2) {
  couvercle();
} else if (part == 3) {
  plaque_murale();
} else {
  // vue eclatee
  corps();
  translate([0, 0, depth + 8]) couvercle();
  translate([0, 0, depth + 30]) plaque_murale();
}

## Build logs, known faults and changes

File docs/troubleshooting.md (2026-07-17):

# Troubleshooting

Real issues encountered and solved while building this project.

## Camera stays in "waiting for download" (no WiFi AP appears)

**Symptom**: serial log shows `boot:0x3 (DOWNLOAD_BOOT)` / `waiting for download`.
**Cause**: the GPIO 0 → GND flashing jumper is still in place.
**Fix**: remove the jumper, press RESET. Flashing jumper is only needed during upload.

## Camera/monitor unreachable on the LAN (works on other devices)

**Symptom**: `ping` and browser fail from one PC, but the device answers from others.
**Cause**: a VPN client (e.g. Tailscale) has installed a route for your LAN subnet (`192.168.1.0/24`), hijacking local traffic into the tunnel.
**Fix**: disable the subnet route in the VPN client (Tailscale → *Use Tailscale subnets* → uncheck your LAN), or disconnect the VPN.

## Telegram commands are ignored (but bot answers at boot)

**Cause**: chat ID mismatch — e.g. wrong value, or a parsing bug. The camera only accepts commands from the configured `chat_id`.
**Fix**: verify the chat ID with **@userinfobot** and re-enter it in `http://<ip>/setup`.

## Camera probe fails from the monitor ("no camera at this IP")

**Symptom**: manual add fails while the camera works in a browser.
**Cause**: probe timeout too short — the camera is busy streaming to another client.
**Fix**: close other streams and retry; the firmware ships with a 2 s timeout for manual add and 600 ms for network scans.

## Viewer screen is white after flashing

**Cause**: wrong PSRAM setting.
**Fix**: recompile with `PSRAM=opi` and the correct flash size (8M for N8R8, 16M for N16R8).

## Touch works but axes are inverted

**Fix**: adjust `cfg.offset_rotation` (0–7) in the LGFX touch config block of the monitor firmware.

## Brownouts / random restarts while streaming

**Cause**: power supply too weak. Streaming + WiFi peaks > 500 mA.
**Fix**: use a dedicated 5 V / 2 A supply and a short, good-quality cable.

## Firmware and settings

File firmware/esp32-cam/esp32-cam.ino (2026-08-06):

/*
 * ESP32-CAM Surveillance intelligente v3 — CORRIGÉ COMPLET
 * ----------------------------------------------------------
 * Corrections (audit Kimi + Claude Opus) :
 *   • Mutex caméra (camGet/camReturn) — driver non réentrant
 *   • lastUpdateId persisté en NVS — évite boucle reboot infinie
 *   • Mode AP avec retry WiFi toutes les 2 min — plus de caméra morte
 *   • camera_config_t config = {} — initialisation complète
 *   • Double serveur HTTP : port 80 (API) + port 81 (stream dédié)
 *   • AVI fps réels mesurés — plus de vidéo accélérée
 *   • Rotation SD automatique — suppression anciens .avi
 *   • Token Telegram masqué dans le formulaire
 *   • Auth API (X-Auth-Token) sur routes sensibles
 *   • Ghost Mode : 5s analyse silencieuse avant alerte
 *   • Task Telegram dédiée sur core 0 — loop jamais bloqué
 *   • Watchdog natif ESP32 — remplace watchdog custom buggé
 *   • PortEXIT/ENTER_CRITICAL sur toutes les variables partagées
 *   • Buffer overflow fix dans save_handler
 *   • Path traversal fix dans dl_handler
 *   • Échappement HTML/JSON (XSS/Injection)
 *   • Division par zéro protégée
 *
 * Carte : AI Thinker ESP32-CAM (clone Binghe) + camera OV3660
 * Carte microSD : FAT32 (mode 1-bit : GPIO 12/13 libres pour HC-SR04)
 */

#include "esp_camera.h"
#include <WiFi.h>
#include <WiFiClientSecure.h>
#include "esp_http_server.h"
#include "FS.h"
#include "SD_MMC.h"
#include "time.h"
#include <Preferences.h>
#include <ESPmDNS.h>
#include "esp_task_wdt.h"
#include "soc/rtc_cntl_reg.h"
#include "avi_writer.h"

// ================ CONFIGURATION ================
const bool  DETECTION_ULTRASON      = false;
const bool  DETECTION_PIR           = true;   // SR602 PIR sensor
const float HYSTERESIS_CM           = 20.0;
const int   MESURES_CONFIRMATION    = 3;
const unsigned long INTERVALLE_MESURE_MS = 250;
const unsigned long COOLDOWN_MS          = 30000;

const uint8_t  REC_FPS     = 10;
const unsigned long REC_MIN_MS = 5000;
const unsigned long REC_MAX_MS = 30000;
const size_t MAX_UPLOAD_TELEGRAM = 18UL * 1024 * 1024;

const unsigned long TELEGRAM_POLL_MS = 3000;
const int WDT_TIMEOUT_S = 60;

// Ghost Mode
const bool  GHOST_MODE_ENABLED      = true;
const unsigned long GHOST_ANALYZE_MS = 5000;
const int   GHOST_MIN_HITS          = 4;

// Pins
#define TRIG_PIN 13
#define ECHO_PIN 12
#define PIR_PIN  14   // SR602 PIR sensor
#define FLASH_LED_PIN 4
#define REC_LED_PIN   33
#define EXT_LED_PIN 4
const int LED_NUIT_DEBUT = 18;
const int LED_NUIT_FIN   = 7;
#define FLASH_PENDANT_CAPTURE false

// =================== PINS CAMERA (AI Thinker / Binghe) ==============
#define PWDN_GPIO_NUM     32
#define RESET_GPIO_NUM    -1
#define XCLK_GPIO_NUM      0
#define SIOD_GPIO_NUM     26
#define SIOC_GPIO_NUM     27
#define Y9_GPIO_NUM       35
#define Y8_GPIO_NUM       34
#define Y7_GPIO_NUM       39
#define Y6_GPIO_NUM       36
#define Y5_GPIO_NUM       21
#define Y4_GPIO_NUM       19
#define Y3_GPIO_NUM       18
#define Y2_GPIO_NUM        5
#define VSYNC_GPIO_NUM    25
#define HREF_GPIO_NUM     23
#define PCLK_GPIO_NUM     22

// =================== MUTEX & ÉTAT GLOBAL ===================
portMUX_TYPE streamMux = portMUX_INITIALIZER_UNLOCKED;
portMUX_TYPE stateMux  = portMUX_INITIALIZER_UNLOCKED;
SemaphoreHandle_t camMutex = NULL;

bool configMode = false;
String cfgSsid, cfgPass, cfgToken, cfgChatId, cfgCamName = "ESP32-CAM", cfgApiToken;
float cfgSeuil = 100.0;

bool sdReady = false;
bool detectionActive = true;
bool recording = false;
String lastVideoPath;
int videoCount = 0;
float lastDistance = -1;
uint16_t frameW = 800, frameH = 600;

File aviFile;
AVIWriter avi;
unsigned long recStartMs = 0;
unsigned long lastRecFrameMs = 0;
unsigned long lastPresenceMs = 0;
int absenceCount = 0;

long lastUpdateId = 0;
unsigned long lastPollMs = 0;
int compteurDetection = 0;
unsigned long lastMeasureMs = 0;
unsigned long lastAlertMs = 0;

bool ledState = false;
bool ledManual = false;
unsigned long ledAutoOffAt = 0;

// Ghost Mode state (protégé par stateMux)
bool ghostAnalyzing = false;
unsigned long ghostStartMs = 0;
int ghostHitCount = 0;
String ghostVideoPath;
bool ghostRecording = false;

// Stream clients (protégé par streamMux)
volatile int streamClients = 0;

// Watchdog timestamps
unsigned long lastLoopAliveMs = 0;
unsigned long lastFrameOkMs = 0;
unsigned long lastWifiOkMs = 0;

// Telegram task handle
TaskHandle_t telegramTaskHandle = NULL;

// ================ MUTEX CAMÉRA =================

camera_fb_t* camGet(uint32_t timeoutMs = 2000) {
  if (!camMutex) return esp_camera_fb_get();
  if (xSemaphoreTake(camMutex, pdMS_TO_TICKS(timeoutMs)) != pdTRUE) return NULL;
  camera_fb_t* fb = esp_camera_fb_get();
  if (!fb) xSemaphoreGive(camMutex);
  return fb;
}

void camReturn(camera_fb_t* fb) {
  if (!fb) return;
  esp_camera_fb_return(fb);
  if (camMutex) xSemaphoreGive(camMutex);
}

// ================ UTILITAIRES =================

String urlDecode(const String& s) {
  String out;
  for (size_t i = 0; i < s.length(); i++) {
    if (s[i] == '+') out += ' ';
    else if (s[i] == '%' && i + 2 < s.length()) {
      char h[3] = { s[i + 1], s[i + 2], 0 };
      out += (char)strtol(h, NULL, 16);
      i += 2;
    } else out += s[i];
  }
  return out;
}

String postParam(const String& body, const char* key) {
  String k = String(key) + "=";
  int i = body.indexOf(k);
  if (i < 0) return "";
  int start = i + k.length();
  int end = body.indexOf('&', start);
  if (end < 0) end = body.length();
  return urlDecode(body.substring(start, end));
}

String escapeHTML(const String& s) {
  String out;
  out.reserve(s.length() + 16);
  for (size_t i = 0; i < s.length(); i++) {
    char c = s[i];
    if (c == '<') out += "&lt;";
    else if (c == '>') out += "&gt;";
    else if (c == '&') out += "&amp;";
    else if (c == '"') out += "&quot;";
    else if (c == '\'') out += "&#x27;";
    else out += c;
  }
  return out;
}

String escapeJSON(const String& s) {
  String out;
  out.reserve(s.length() + 16);
  for (size_t i = 0; i < s.length(); i++) {
    char c = s[i];
    if (c == '"') out += "\\\"";
    else if (c == '\\') out += "\\\\";
    else if (c == '\b') out += "\\b";
    else if (c == '\f') out += "\\f";
    else if (c == '\n') out += "\\n";
    else if (c == '\r') out += "\\r";
    else if (c == '\t') out += "\\t";
    else out += c;
  }
  return out;
}

// ================ CONFIGURATION (flash + portail) =================

void loadConfig() {
  Preferences prefs;
  prefs.begin("camcfg", true);
  cfgSsid     = prefs.getString("ssid", "");
  cfgPass     = prefs.getString("pass", "");
  cfgToken    = prefs.getString("token", "");
  cfgChatId   = prefs.getString("chatid", "");
  cfgCamName  = prefs.getString("name", "ESP32-CAM");
  cfgSeuil    = prefs.getFloat("seuil", 100.0);
  cfgApiToken = prefs.getString("apitoken", "");
  lastUpdateId = prefs.getLong("lastupd", 0);
  prefs.end();
}

void saveConfig() {
  Preferences prefs;
  prefs.begin("camcfg", false);
  prefs.putString("ssid", cfgSsid);
  prefs.putString("pass", cfgPass);
  prefs.putString("token", cfgToken);
  prefs.putString("chatid", cfgChatId);
  prefs.putString("name", cfgCamName);
  prefs.putFloat("seuil", cfgSeuil);
  prefs.putString("apitoken", cfgApiToken);
  prefs.end();
}

void saveUpdateId(long id) {
  Preferences prefs;
  prefs.begin("camcfg", false);
  prefs.putLong("lastupd", id);
  prefs.end();
}

// ================ AUTHENTIFICATION =================

bool checkAuth(httpd_req_t* req) {
  if (cfgApiToken.length() == 0) return true;
  char buf[64];
  if (httpd_req_get_hdr_value_str(req, "X-Auth-Token", buf, sizeof(buf)) == ESP_OK) {
    if (String(buf) == cfgApiToken) return true;
  }
  char query[128];
  if (httpd_req_get_url_query_str(req, query, sizeof(query)) == ESP_OK) {
    char val[64];
    if (httpd_query_key_value(query, "token", val, sizeof(val)) == ESP_OK) {
      if (String(val) == cfgApiToken) return true;
    }
  }
  httpd_resp_set_status(req, "403 Forbidden");
  httpd_resp_set_hdr(req, "Access-Control-Allow-Origin", "*");
  httpd_resp_send(req, "Forbidden", HTTPD_RESP_USE_STRLEN);
  return false;
}

// ================ PAGES WEB =================

String configPage() {
  String h = F("<!DOCTYPE html><html><head><meta charset='utf-8'>"
    "<meta name='viewport' content='width=device-width,initial-scale=1'>"
    "<title>ESP32-CAM Config</title><style>"
    "body{font-family:sans-serif;background:#111;color:#eee;max-width:420px;margin:20px auto;padding:0 15px}"
    "input{width:100%;padding:10px;margin:5px 0 15px;border-radius:6px;border:1px solid #444;background:#222;color:#eee;box-sizing:border-box}"
    "button{width:100%;padding:12px;background:#1976d2;color:#fff;border:0;border-radius:6px;font-size:16px;cursor:pointer}"
    "label{color:#aaa;font-size:14px}h2{text-align:center}"
    ".info{background:#1b3a1b;padding:10px;border-radius:6px;font-size:13px;margin-bottom:15px}"
    ".warn{background:#3a1b1b;padding:10px;border-radius:6px;font-size:13px;margin-bottom:15px}"
    "</style></head><body>");
  h += "<h2>&#x1F4F7; Configuration ESP32-CAM</h2>";
  if (configMode) h += "<div class='info'>&#x1F4E1; La camera n'a pas pu se connecter au WiFi. Remplis ce formulaire : elle redemarrera sur ton reseau.</div>";
  if (cfgApiToken.length() == 0) h += "<div class='warn'>&#x26A0; Securite : definis un token API ci-dessous pour proteger le stream et la config !</div>";
  h += F("<form method='POST' action='/save'>"
    "<label>Nom du reseau WiFi (SSID)</label>"
    "<input name='ssid' list='nets' value='");
  h += escapeHTML(cfgSsid);
  h += F("' required><datalist id='nets'></datalist>"
    "<label>Mot de passe WiFi</label>"
    "<input name='pass' type='password' placeholder='(laisser vide = inchange)'>"
    "<label>Token bot Telegram (@BotFather)</label>"
    "<input name='token' type='password' placeholder='");
  h += cfgToken.length() ? F("(deja configure - laisser vide = inchange)") : F("123456:ABC-...");
  h += F("'>"
    "<label>Chat ID Telegram</label>"
    "<input name='chatid' value='");
  h += escapeHTML(cfgChatId);
  h += F("'>"
    "<label>Nom de la camera</label>"
    "<input name='name' value='");
  h += escapeHTML(cfgCamName);
  h += F("'>"
    "<label>Distance de detection (cm)</label>"
    "<input name='seuil' type='number' value='");
  h += String((int)cfgSeuil);
  h += F("'>"
    "<label>Token API (securite : stream + config)</label>"
    "<input name='apitoken' placeholder='laisser vide = desactive' value='");
  h += escapeHTML(cfgApiToken);
  h += F("'>"
    "<button type='submit'>&#x1F4BE; Enregistrer et redemarrer</button></form>"
    "<p style='color:#777;font-size:13px'>Bot : @BotFather &rarr; /newbot &rarr; token.<br>"
    "Chat ID : envoie un message au bot puis ouvre api.telegram.org/bot&lt;TOKEN&gt;/getUpdates</p>"
    "<script>fetch('/scan').then(r=>r.json()).then(d=>{var dl=document.getElementById('nets');"
    "d.forEach(function(n){var o=document.createElement('option');o.value=n.ssid;o.label=n.rssi+' dBm';dl.appendChild(o);});});</script>"
    "</body></html>");
  return h;
}

static esp_err_t config_handler(httpd_req_t* req) {
  if (!checkAuth(req)) return ESP_FAIL;
  httpd_resp_set_type(req, "text/html");
  String page = configPage();
  return httpd_resp_send(req, page.c_str(), page.length());
}

static esp_err_t scan_handler(httpd_req_t* req) {
  httpd_resp_set_type(req, "application/json");
  int n = WiFi.scanNetworks();
  if (n > 20) n = 20;
  String json = "[";
  for (int i = 0; i < n; i++) {
    if (i) json += ",";
    json += "{\"ssid\":\"" + escapeJSON(WiFi.SSID(i)) + "\",\"rssi\":" + String(WiFi.RSSI(i)) + "}";
  }
  json += "]";
  WiFi.scanDelete();
  return httpd_resp_send(req, json.c_str(), json.length());
}

static esp_err_t save_handler(httpd_req_t* req) {
  if (!checkAuth(req)) return ESP_FAIL;
  char buf[1024];
  int len = min((int)sizeof(buf) - 1, (int)req->content_len);
  int ret = httpd_req_recv(req, buf, len);
  if (ret <= 0) { httpd_resp_send_500(req); return ESP_FAIL; }
  if (ret >= (int)sizeof(buf)) ret = (int)sizeof(buf) - 1;
  buf[ret] = '\0';
  String body = buf;

  String s = postParam(body, "ssid");
  if (s.length()) cfgSsid = s;
  s = postParam(body, "pass");
  if (s.length()) cfgPass = s;
  s = postParam(body, "token");
  if (s.length()) cfgToken = s;
  s = postParam(body, "chatid");
  if (s.length()) cfgChatId = s;
  s = postParam(body, "name");
  if (s.length()) cfgCamName = s;
  s = postParam(body, "seuil");
  if (s.length()) cfgSeuil = s.toFloat();
  s = postParam(body, "apitoken");
  cfgApiToken = s;
  saveConfig();

  httpd_resp_set_type(req, "text/html");
  httpd_resp_send(req,
    "<html><head><meta charset='utf-8'></head>"
    "<body style='font-family:sans-serif;background:#111;color:#eee;text-align:center;padding-top:50px'>"
    "<h2>&#x2705; Configuration sauvegardee !</h2>"
    "<p>Redemarrage... La camera rejoint ton WiFi.</p></body></html>",
    HTTPD_RESP_USE_STRLEN);
  delay(2000);
  ESP.restart();
  return ESP_OK;
}

// ================ PORTAIL DE CONFIGURATION =================

void startConfigPortal() {
  configMode = true;
  String mac = WiFi.macAddress();
  String apName = "ESP32-CAM-Setup-" + mac.substring(12, 14) + mac.substring(15, 17);
  WiFi.mode(WIFI_AP_STA);
  WiFi.softAP(apName.c_str(), "12345678");
  Serial.println("\n=== MODE CONFIGURATION ===");
  Serial.println("Reseau WiFi : " + apName + "  (mot de passe : 12345678)");
  Serial.print("Portail : http://");
  Serial.println(WiFi.softAPIP());

  httpd_config_t config = HTTPD_DEFAULT_CONFIG();
  config.server_port = 80;
  config.max_uri_handlers = 4;
  config.max_open_sockets = 4;
  config.ctrl_port = 32768;
  httpd_handle_t server = NULL;
  httpd_uri_t form = { .uri = "/",     .method = HTTP_GET,  .handler = config_handler, .user_ctx = NULL };
  httpd_uri_t scan = { .uri = "/scan", .method = HTTP_GET,  .handler = scan_handler,   .user_ctx = NULL };
  httpd_uri_t save = { .uri = "/save", .method = HTTP_POST, .handler = save_handler,   .user_ctx = NULL };
  if (httpd_start(&server, &config) == ESP_OK) {
    httpd_register_uri_handler(server, &form);
    httpd_register_uri_handler(server, &scan);
    httpd_register_uri_handler(server, &save);
    Serial.println("Portail HTTP demarre");
  }
}

// ================ TELEGRAM =================

String urlencode(const String& s) {
  String out;
  out.reserve(s.length() * 2);
  for (size_t i = 0; i < s.length(); i++) {
    char c = s[i];
    if (isalnum((uint8_t)c) || c == '-' || c == '_' || c == '.' || c == '~') {
      out += c;
    } else {
      char buf[4];
      snprintf(buf, sizeof(buf), "%%%02X", (uint8_t)c);
      out += buf;
    }
  }
  return out;
}

bool telegramSendMessage(const String& text) {
  if (cfgToken.length() == 0 || cfgChatId.length() == 0) return false;
  WiFiClientSecure client;
  client.setInsecure();
  if (!client.connect("api.telegram.org", 443)) return false;
  String url = "/bot" + cfgToken + "/sendMessage?chat_id=" + cfgChatId +
               "&text=" + urlencode(text);
  client.print("GET " + url + " HTTP/1.1\r\nHost: api.telegram.org\r\nConnection: close\r\n\r\n");
  unsigned long start = millis();
  while (client.connected() && !client.available() && millis() - start < 8000) {
    delay(10);
    lastLoopAliveMs = millis();  // nourrir watchdog pendant l'attente
  }
  String resp;
  while (client.available()) resp += (char)client.read();
  client.stop();
  return resp.indexOf("\"ok\":true") >= 0;
}
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
void loop() {
  esp_task_wdt_reset();
  lastLoopAliveMs = millis();

  // ---------- MODE CONFIG : retry WiFi toutes les 2 min ----------
  if (configMode) {
    static unsigned long lastTry = 0;
    if (cfgSsid.length() > 0 && millis() - lastTry > 120000) {
      lastTry = millis();
      Serial.println("Portail actif : nouvelle tentative WiFi...");
      WiFi.begin(cfgSsid.c_str(), cfgPass.c_str());
      unsigned long t0 = millis();
      while (WiFi.status() != WL_CONNECTED && millis() - t0 < 12000) {
        delay(200);
        lastLoopAliveMs = millis();
        esp_task_wdt_reset();
      }
      if (WiFi.status() == WL_CONNECTED) {
        Serial.println("WiFi retrouve -> redemarrage en mode normal");
        delay(500);
        ESP.restart();
      }
    }
    delay(50);
    return;
  }

  unsigned long now = millis();

  // ---------- reconnexion WiFi automatique ----------
  static unsigned long lastWifiRetry = 0;
  if (WiFi.status() != WL_CONNECTED && now - lastWifiRetry > 30000) {
    lastWifiRetry = now;
    Serial.println("WiFi perdu, tentative de reconnexion...");
    WiFi.disconnect();
    WiFi.reconnect();
  }
  if (WiFi.status() == WL_CONNECTED) {
    lastWifiOkMs = now;
  }

  // ---------- extinction auto LED ----------
  if (ledAutoOffAt > 0 && now >= ledAutoOffAt) {
    portENTER_CRITICAL(&stateMux);
    bool rec = recording;
    bool lman = ledManual;
    portEXIT_CRITICAL(&stateMux);
    if (!rec && !lman) {
      ledAutoOffAt = 0;
      ledSet(false);
    }
  }

  // ---------- detection PIR (SR602) ----------\n  if (DETECTION_PIR) {\n    static bool pirLast = false;\n    bool pirNow = digitalRead(PIR_PIN);\n    \n    // Front montant: mouvement detecte\n    if (pirNow && !pirLast) {\n      if (GHOST_MODE_ENABLED && !ghostAnalyzing && !recording) {\n        startGhostRecording();\n      }\n    }\n    \n    // PIR actif pendant Ghost Mode: incrementer hits\n    if (pirNow && GHOST_MODE_ENABLED && ghostAnalyzing) {\n      portENTER_CRITICAL(&stateMux);\n      ghostHitCount++;\n      portEXIT_CRITICAL(&stateMux);\n    }\n    pirLast = pirNow;\n  }\n\n  // ---------- Ghost Mode : decision ----------
  if (GHOST_MODE_ENABLED && ghostAnalyzing) {
    if (now - ghostStartMs >= GHOST_ANALYZE_MS) {
      portENTER_CRITICAL(&stateMux);
      int hits = ghostHitCount;
      portEXIT_CRITICAL(&stateMux);
      if (hits >= GHOST_MIN_HITS) {
        stopGhostRecording(true);
      } else {
        stopGhostRecording(false);
      }
    }
  }

  // ---------- mesure ultrason ----------
  if (DETECTION_ULTRASON && now - lastMeasureMs >= INTERVALLE_MESURE_MS) {
    lastMeasureMs = now;
    float d = readDistanceCM();
    lastDistance = d;

    if (d > 0 && d <= cfgSeuil) {
      compteurDetection++;
      if (GHOST_MODE_ENABLED && ghostAnalyzing) {
        portENTER_CRITICAL(&stateMux);
        ghostHitCount++;
        portEXIT_CRITICAL(&stateMux);
      }
      Serial.printf("Detection %.0f cm (%d/%d)\n", d, compteurDetection, MESURES_CONFIRMATION);
    } else {
      compteurDetection = 0;
    }

    portENTER_CRITICAL(&stateMux);
    bool rec = recording;
    bool grec = ghostRecording;
    bool ganal = ghostAnalyzing;
    portEXIT_CRITICAL(&stateMux);

    if (detectionActive && !rec && !ganal &&
        compteurDetection >= MESURES_CONFIRMATION &&
        now - lastAlertMs >= COOLDOWN_MS) {
      lastAlertMs = now;
      compteurDetection = 0;
      if (GHOST_MODE_ENABLED) {
        startGhostRecording();
      } else {
        sendAlert(d);
        startRecording();
      }
    }
  }

  // ---------- enregistrement video (normal ou ghost) ----------
  portENTER_CRITICAL(&stateMux);
  bool rec = recording;
  bool grec = ghostRecording;
  portEXIT_CRITICAL(&stateMux);

  if (rec || grec) {
    unsigned long frameInterval = (REC_FPS > 0) ? (1000 / REC_FPS) : 100;
    if (now - lastRecFrameMs >= frameInterval) {
      lastRecFrameMs = now;
      camera_fb_t* fb = camGet();
      if (fb) {
        lastFrameOkMs = millis();
        if (!avi.addFrame(fb->buf, fb->len)) {
          if (grec) stopGhostRecording(false);
          else stopRecording();
        }
        camReturn(fb);
      }
    }
    // Verification presence uniquement en mode normal (pas ghost)
    if (rec && !grec && now - lastPresenceMs >= 500) {
      lastPresenceMs = now;
      float d = readDistanceCM();
      if (d < 0 || d > cfgSeuil + HYSTERESIS_CM) absenceCount++;
      else absenceCount = 0;
      unsigned long duree = now - recStartMs;
      if ((absenceCount >= 2 && duree >= REC_MIN_MS) || duree >= REC_MAX_MS) {
        stopRecording();
      }
    }
  }

  delay(1);
}

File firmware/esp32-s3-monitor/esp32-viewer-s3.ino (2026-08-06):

/*
 * ESP32-S3 4827S043 — Moniteur multi-cameras tactile v2
 * ------------------------------------------------------
 * - Portail web de configuration WiFi (rien a coder)
 * - AUTO-SCAN du reseau : detecte les ESP32-CAM tout seul
 * - Clavier tactile : ajout manuel d'une camera par IP
 * - Vue grille multi-cams + plein ecran au tap
 *
 * Hardware : ESP32-4827S043C (ecran RGB 480x272 + tactile GT911)
 * Librairie : LovyanGFX
 */

#define LGFX_USE_V1
#include <LovyanGFX.hpp>
#include <lgfx/v1/platforms/esp32s3/Panel_RGB.hpp>
#include <lgfx/v1/platforms/esp32s3/Bus_RGB.hpp>
#include <driver/i2c.h>
#include <WiFi.h>
#include <HTTPClient.h>
#include <Preferences.h>
#include <ESPmDNS.h>
#include "esp_http_server.h"
#include "esp_heap_caps.h"

// ===================== CONFIGURATION =====================
// Rien a modifier ici : le WiFi se configure via le portail web,
// les cameras via l'ecran tactile (scan auto ou ajout manuel).

const int MAX_CAMS = 4;
const unsigned long GRID_CYCLE_MS = 900;    // tour complet de la grille
const int HTTP_TIMEOUT_MS = 2500;
const int PROBE_TIMEOUT_MS = 600;           // timeout par IP pendant le scan
const int ADD_TIMEOUT_MS = 2000;            // timeout pour l'ajout manuel (IP precise)

// ============ DRIVER ECRAN : ESP32-4827S043 (480x272 RGB) ===========

class LGFX : public lgfx::LGFX_Device {
public:
  lgfx::Bus_RGB     _bus_instance;
  lgfx::Panel_RGB   _panel_instance;
  lgfx::Light_PWM   _light_instance;
  lgfx::Touch_GT911 _touch_instance;

  LGFX(void) {
    {
      auto cfg = _panel_instance.config();
      cfg.memory_width  = 480;
      cfg.memory_height = 272;
      cfg.panel_width   = 480;
      cfg.panel_height  = 272;
      cfg.offset_x = 0;
      cfg.offset_y = 0;
      _panel_instance.config(cfg);
    }
    {
      auto cfg = _panel_instance.config_detail();
      cfg.use_psram = 1;
      _panel_instance.config_detail(cfg);
    }
    {
      auto cfg = _bus_instance.config();
      cfg.panel = &_panel_instance;
      cfg.pin_d0  = GPIO_NUM_8;   // B0
      cfg.pin_d1  = GPIO_NUM_3;   // B1
      cfg.pin_d2  = GPIO_NUM_46;  // B2
      cfg.pin_d3  = GPIO_NUM_9;   // B3
      cfg.pin_d4  = GPIO_NUM_1;   // B4
      cfg.pin_d5  = GPIO_NUM_5;   // G0
      cfg.pin_d6  = GPIO_NUM_6;   // G1
      cfg.pin_d7  = GPIO_NUM_7;   // G2
      cfg.pin_d8  = GPIO_NUM_15;  // G3
      cfg.pin_d9  = GPIO_NUM_16;  // G4
      cfg.pin_d10 = GPIO_NUM_4;   // G5
      cfg.pin_d11 = GPIO_NUM_45;  // R0
      cfg.pin_d12 = GPIO_NUM_48;  // R1
      cfg.pin_d13 = GPIO_NUM_47;  // R2
      cfg.pin_d14 = GPIO_NUM_21;  // R3
      cfg.pin_d15 = GPIO_NUM_14;  // R4
      cfg.pin_henable = GPIO_NUM_40;  // DE
      cfg.pin_vsync   = GPIO_NUM_41;
      cfg.pin_hsync   = GPIO_NUM_39;
      cfg.pin_pclk    = GPIO_NUM_42;
      cfg.freq_write  = 9000000;
      cfg.hsync_polarity    = 0;
      cfg.hsync_front_porch = 1;
      cfg.hsync_pulse_width = 1;
      cfg.hsync_back_porch  = 43;
      cfg.vsync_polarity    = 0;
      cfg.vsync_front_porch = 3;
      cfg.vsync_pulse_width = 1;
      cfg.vsync_back_porch  = 12;
      cfg.pclk_active_neg   = 1;
      _bus_instance.config(cfg);
    }
    _panel_instance.setBus(&_bus_instance);
    {
      auto cfg = _light_instance.config();
      cfg.pin_bl = GPIO_NUM_2;
      _light_instance.config(cfg);
    }
    _panel_instance.light(&_light_instance);
    {
      auto cfg = _touch_instance.config();
      cfg.x_min = 0;
      cfg.x_max = 480;
      cfg.y_min = 0;
      cfg.y_max = 272;
      cfg.pin_int = GPIO_NUM_18;
      cfg.pin_rst = GPIO_NUM_38;
      cfg.bus_shared = false;
      cfg.offset_rotation = 0;
      cfg.i2c_port = I2C_NUM_1;
      cfg.pin_sda = GPIO_NUM_19;
      cfg.pin_scl = GPIO_NUM_20;
      cfg.freq = 400000;
      cfg.i2c_addr = 0x5D;
      _touch_instance.config(cfg);
      _panel_instance.setTouch(&_touch_instance);
    }
    setPanel(&_panel_instance);
  }
};

LGFX tft;

// ============================ ETAT GLOBAL ===========================

struct Cam { String name; String ip; };
Cam cams[4];
int nbCams = 0;

String cfgSsid, cfgPass;
bool configMode = false;

enum ViewMode { MODE_GRID, MODE_FULL, MODE_SCAN, MODE_ADD };
ViewMode viewMode = MODE_GRID;
int fullCamIndex = 0;
bool camOnline[4] = {false, false, false, false};
int gridCursor = 0;
unsigned long lastGridFetch = 0;

// saisie clavier
String inputIp;
String addMessage;
unsigned long addMessageMs = 0;

// bouton effacer (double tap confirmation)
bool pendingClear = false;
unsigned long pendingClearMs = 0;

const size_t JPG_BUF_SIZE = 512 * 1024;  // FIX : UXGA q=6 = 250-450 Ko
uint8_t* jpgBuf = nullptr;
size_t jpgLen = 0;

// ================== CONFIGURATION (flash NVS) =======================

void loadConfig() {
  Preferences prefs;
  prefs.begin("viewer", true);
  cfgSsid = prefs.getString("ssid", "");
  cfgPass = prefs.getString("pass", "");
  prefs.end();
}

void saveWifi() {
  Preferences prefs;
  prefs.begin("viewer", false);
  prefs.putString("ssid", cfgSsid);
  prefs.putString("pass", cfgPass);
  prefs.end();
}

void loadCams() {
  Preferences prefs;
  prefs.begin("viewer", true);
  nbCams = prefs.getUChar("ncam", 0);
  if (nbCams > MAX_CAMS) nbCams = MAX_CAMS;
  for (int i = 0; i < nbCams; i++) {
    cams[i].name = prefs.getString(("cam" + String(i) + "n").c_str(), "");
    cams[i].ip   = prefs.getString(("cam" + String(i) + "i").c_str(), "");
  }
  prefs.end();
}

void saveCams() {
  Preferences prefs;
  prefs.begin("viewer", false);
  prefs.putUChar("ncam", nbCams);
  for (int i = 0; i < nbCams; i++) {
    prefs.putString(("cam" + String(i) + "n").c_str(), cams[i].name);
    prefs.putString(("cam" + String(i) + "i").c_str(), cams[i].ip);
  }
  prefs.end();
}

// ==================== PORTAIL WEB CONFIG WIFI =======================

String urlDecode(const String& s) {
  String out;
  for (size_t i = 0; i < s.length(); i++) {
    if (s[i] == '+') out += ' ';
    else if (s[i] == '%' && i + 2 < s.length()) {
      char h[3] = { s[i + 1], s[i + 2], 0 };
      out += (char)strtol(h, NULL, 16);
      i += 2;
    } else out += s[i];
  }
  return out;
}

String postParam(const String& body, const char* key) {
  String k = String(key) + "=";
  int i = body.indexOf(k);
  if (i < 0) return "";
  int start = i + k.length();
  int end = body.indexOf('&', start);
  if (end < 0) end = body.length();
  return urlDecode(body.substring(start, end));
}
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

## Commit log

2026-07-17 Initial release: ESP32-CAM surveillance system with S3 tactile monitor
    - Camera firmware: MJPEG streaming, Telegram alerts, AVI recording,
    LED lighting (manual + auto night mode), web config portal, watchdog
    - S3 monitor firmware (4827S043): multi-cam grid, full-screen view,
    network auto-scan, on-screen keypad, LED control, web provisioning
    - 3D-printable wall-mount case (OpenSCAD parametric + STLs)
    - English documentation, wiring guides, troubleshooting
    [boitier_4827S043.scad, boitier_corps.stl, boitier_couvercle.stl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]
2026-07-17 feat: mDNS auto-discovery + fix MJPEG full-screen parsing (peek)
    - Cameras now advertise via mDNS (_esp32cam._tcp) and are reachable
    at http://<name>.local
    - Monitor discovers cameras instantly via mDNS query, with IP-scan fallback
    - Fix: full-screen stream parsing no longer consumes the trailing CR
    before the JPEG boundary (used peek), which caused instant fallback
    to grid view
    [esp32-cam-surveillance.ino, esp32-viewer-s3.ino]
2026-07-18 feat: 3D-printable case for ESP32-CAM + MB programming board
    - Parametric OpenSCAD source (thin 1.6mm walls, vertical ribbed texture)
    - Snap-friction lid, no supports needed
    - Lens/flash/USB/SD/antenna openings + M3 mount holes
    - Validated STLs: body, lid, combined plate
    [esp32cam_case_body.stl, esp32cam_case_lid.stl, esp32cam_case_print_all.stl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]
2026-08-06 Heatmap: vraies donnees de detection + endpoint /api/ai/heatmap
2026-08-06 Ollama: prompt ameliore avec contexte horaire et analyse de lumiere (eteinte vs sombre)
2026-08-06 Multi-camera: daemon loops cameras.json + /api/cameras endpoint
2026-08-06 Galerie detections + multi-cameras mosaic view
2026-08-06 v3: corrections securite + Ghost Mode + mutex camera + double HTTP server + fps reels AVI + S3 fixes + hermes-ai securite
    [avi_writer.h, esp32-cam.ino, esp32-viewer-s3.ino]
2026-08-06 v3 firmware: brownout fix + task WDT compat + port 81 stream + API token + .env
    [esp32-cam.ino]
2026-08-06 Dashboard: Live view button (MJPEG fullscreen)
2026-08-06 Live view: LED toggle button
2026-08-06 Fix LED button position (left, not overlapping)
2026-08-06 Fix: camGet retry dans /capture (evite 500 quand stream actif)
    [esp32-cam.ino]
2026-08-08 feat: pipeline AI v3 - anomalies silencieuses + DeepFace fix + daemon hardcore
    - ai_anomaly.py: détection d'anomalies horaires (silencieux si OK)
    - ai_anomaly.sh: déclenche alerte uniquement sur 🚨
    - ai_daemon_hardcore.py: niveau 4 (YOLO → DeepFace → Pose → OWL-ViT)
    - ai_eye_hardcore.py: descriptions YOLO concises, emojis
    - ai_daemon.py: stabilisation WDT + multi-cam
    - ai_eye.py: compatibilité daemon
    - ai_dashboard.html: SSE live + heatmap + compteur
